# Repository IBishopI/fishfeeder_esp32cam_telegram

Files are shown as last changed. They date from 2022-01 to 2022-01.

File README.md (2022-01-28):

# Fish feeder
My Badge

>Fish feeder based on ESP32CAM dev kit and controlled through telegram bot

### Authors: 
[IBishopI](https://github.com/IBishopI) and [Marina Ursu](https://github.com/marinaursu)

## Description:

This project is aimed at people who love:smiling_face_with_three_hearts: aquarium fish:tropical_fish: but spend too much time at work or on business trips.
An autonomous feeder makes it possible to feed your pets from anywhere in the world.

## Capabilities:
- [x]  Set the feeding portion
- [x]  Schedule feeding once a day
- [x]  Take a picture (with and without flash)
- [x]  Find out the status and time of the last feeding
- [X]  (28.01.2022) Clearing the blockage
- [ ]  (further release) Light and thermostat control
- [ ]  (further release) Measurement of water temperature
- [ ]  (further release) Battary cell life-time and life-keeping functions

### Software requirements:
- Arduino IDE 1.8 and higher [here](https://www.arduino.cc/en/software)
- ESP32 core 1.0.6 (most stable for my opinion) [github](https://github.com/espressif/arduino-esp32) or [json](https://raw.githubusercontent.com/espressif/arduino-esp32/gh-pages/package_esp32_index.json)
- [Universal Telegram Bot library](https://github.com/witnessmenow/Universal-Arduino-Telegram-Bot)
- CH340 driver if you will use USBASP programmer with ch340 chip - [Windows](https://sparks.gogo.co.nz/assets/_site_/downloads/CH34x_Install_Windows_v3_4.zip), [Mac](https://github.com/adrianmihalko/ch340g-ch34g-ch34x-mac-os-x-driver/raw/master/CH34x_Install_V1.5.pkg), [Linux](https://sparks.gogo.co.nz/assets/_site_/downloads/CH340_LINUX.zip "Already built in kernel but if isnt you can download it by click this link") or you can findout it on [official website](http://www.wch.cn/download/ch341ser_zip.html)
- Telegram app on your phone:iphone: or laptop:computer:

### Hardware requirements:
- USB ASP progremmer

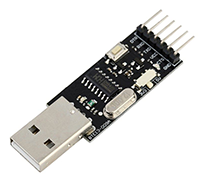
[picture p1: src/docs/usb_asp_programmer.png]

- ESP32cam

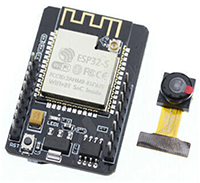
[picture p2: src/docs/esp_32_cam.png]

- Servo

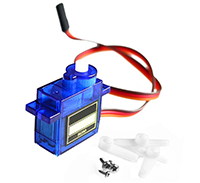
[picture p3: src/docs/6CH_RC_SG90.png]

- DC-DC stepup converter 3.7 to 5v

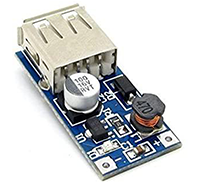
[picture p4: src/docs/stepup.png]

- Battary charger TP4056

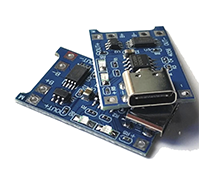
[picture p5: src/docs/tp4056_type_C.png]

- :battery:Li-ion battary cell (18650)

## How to setup telegram bot
> In telegram app find "@BotFather", click/type: /start 
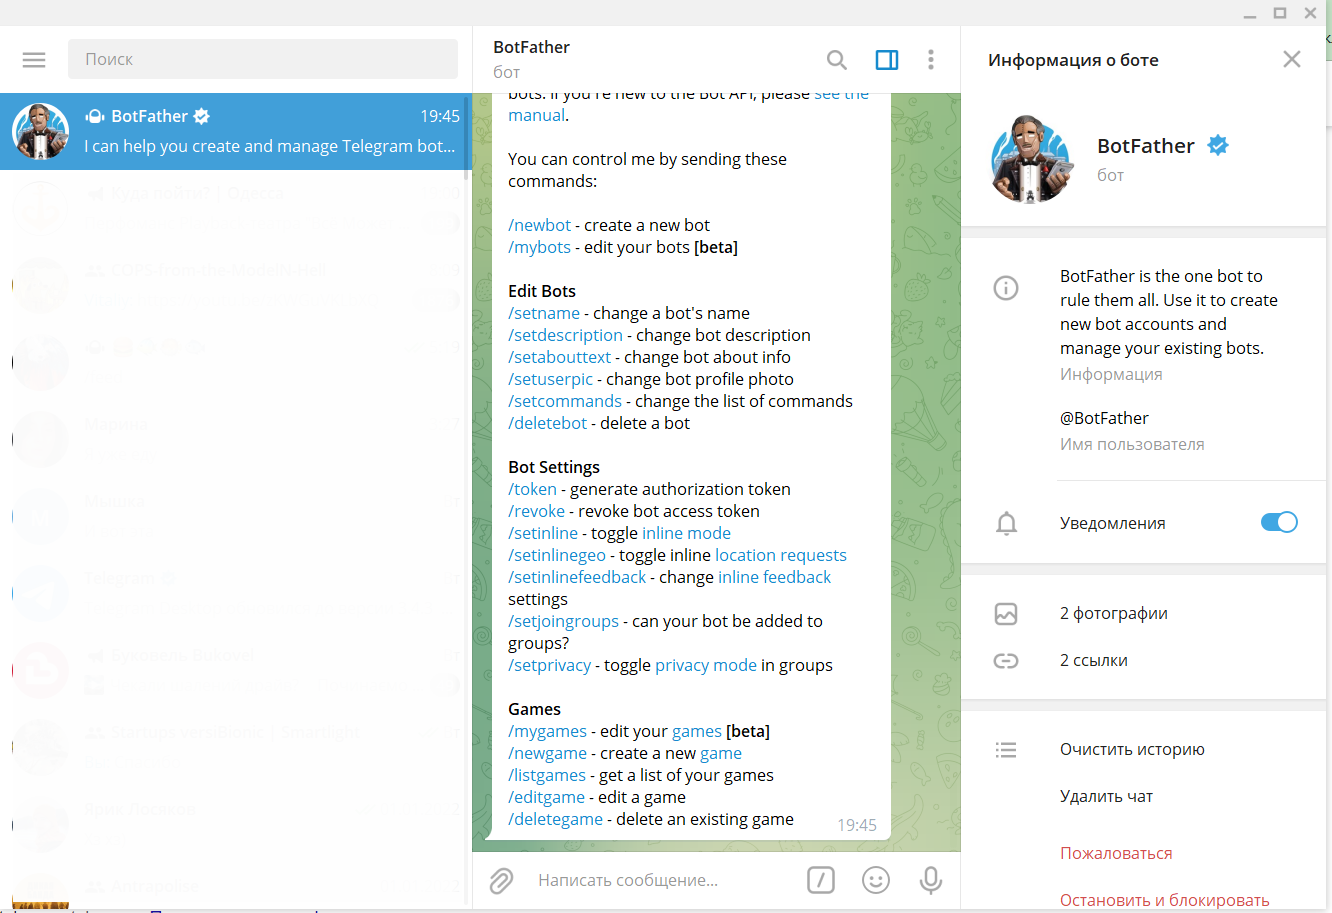
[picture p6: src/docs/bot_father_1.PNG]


> Then click/type command: /newbot
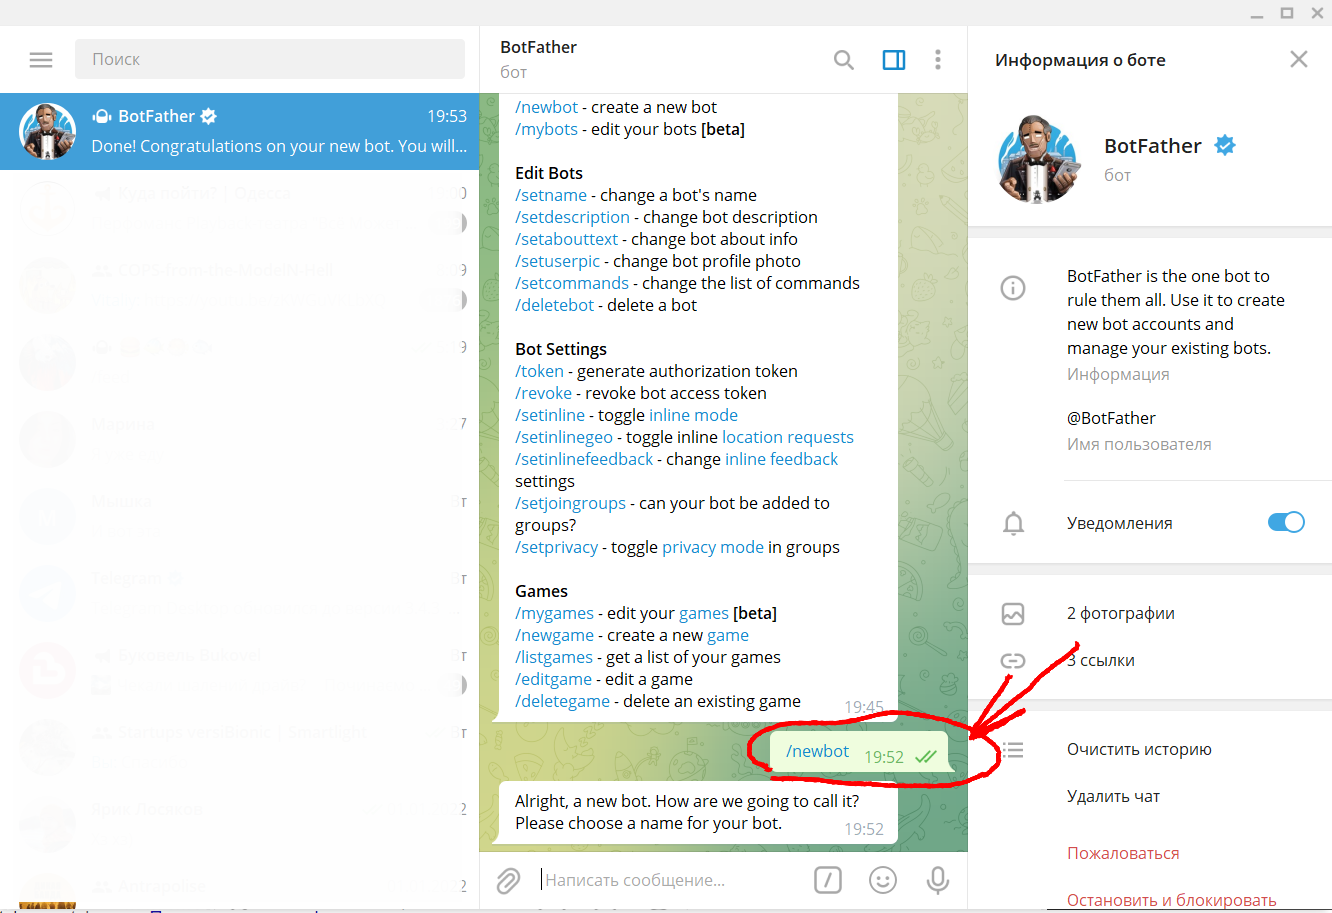
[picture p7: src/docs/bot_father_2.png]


> Then reply to bot's messages, like enter: nickname for bot, username for bot (you can specify any name/username that you want)
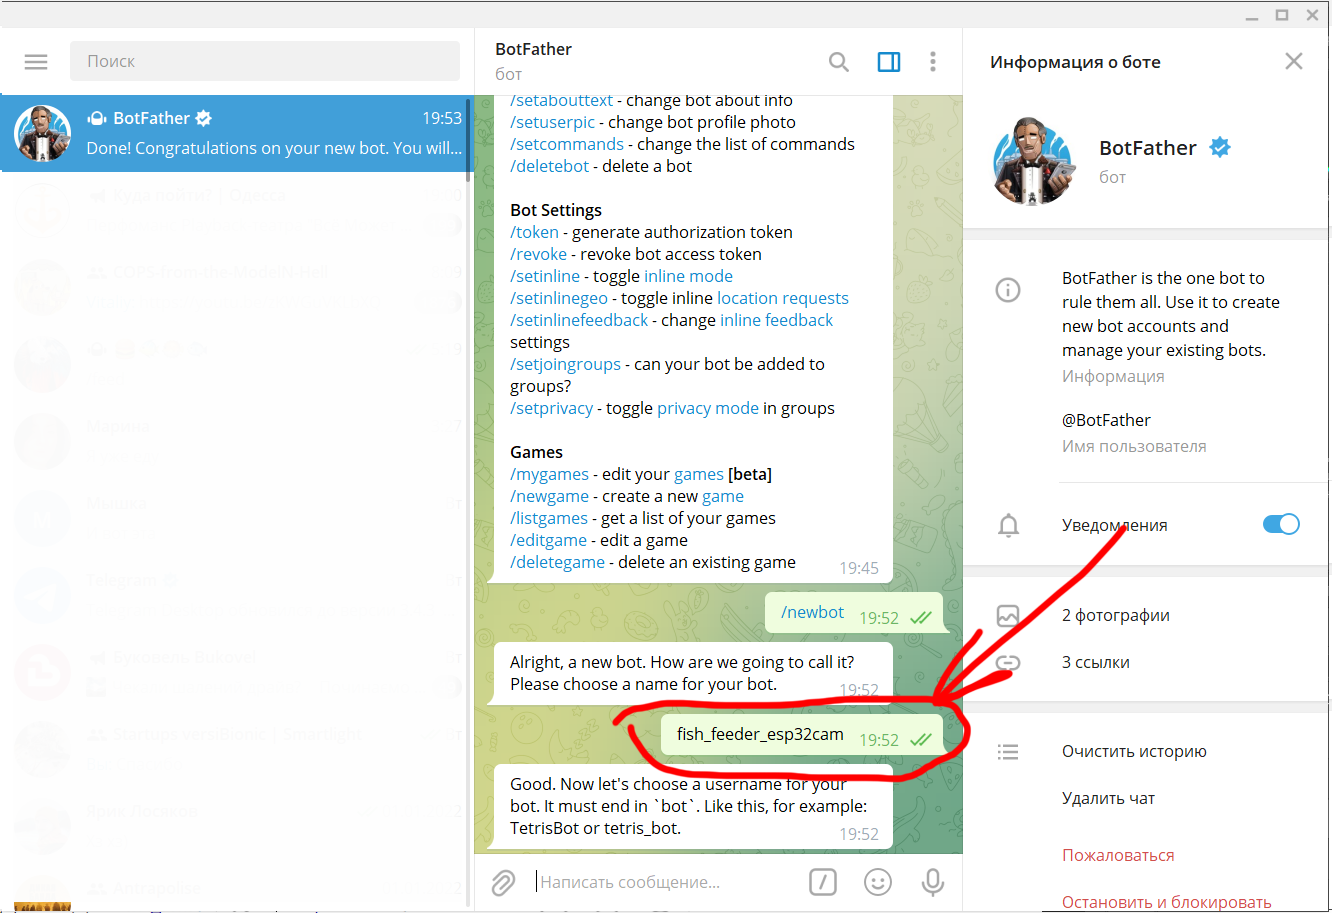
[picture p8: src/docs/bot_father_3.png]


> After that you will get api-token, you should copy it to [this line](https://github.com/IBishopI/fishfeeder_esp32cam_telegram/blob/1f3482a3206f5d00bdcbed5298e4f268f3639a8e/src/Arduino%20IDE%20code/fishfeeder_esp32cam.ino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) in sketch
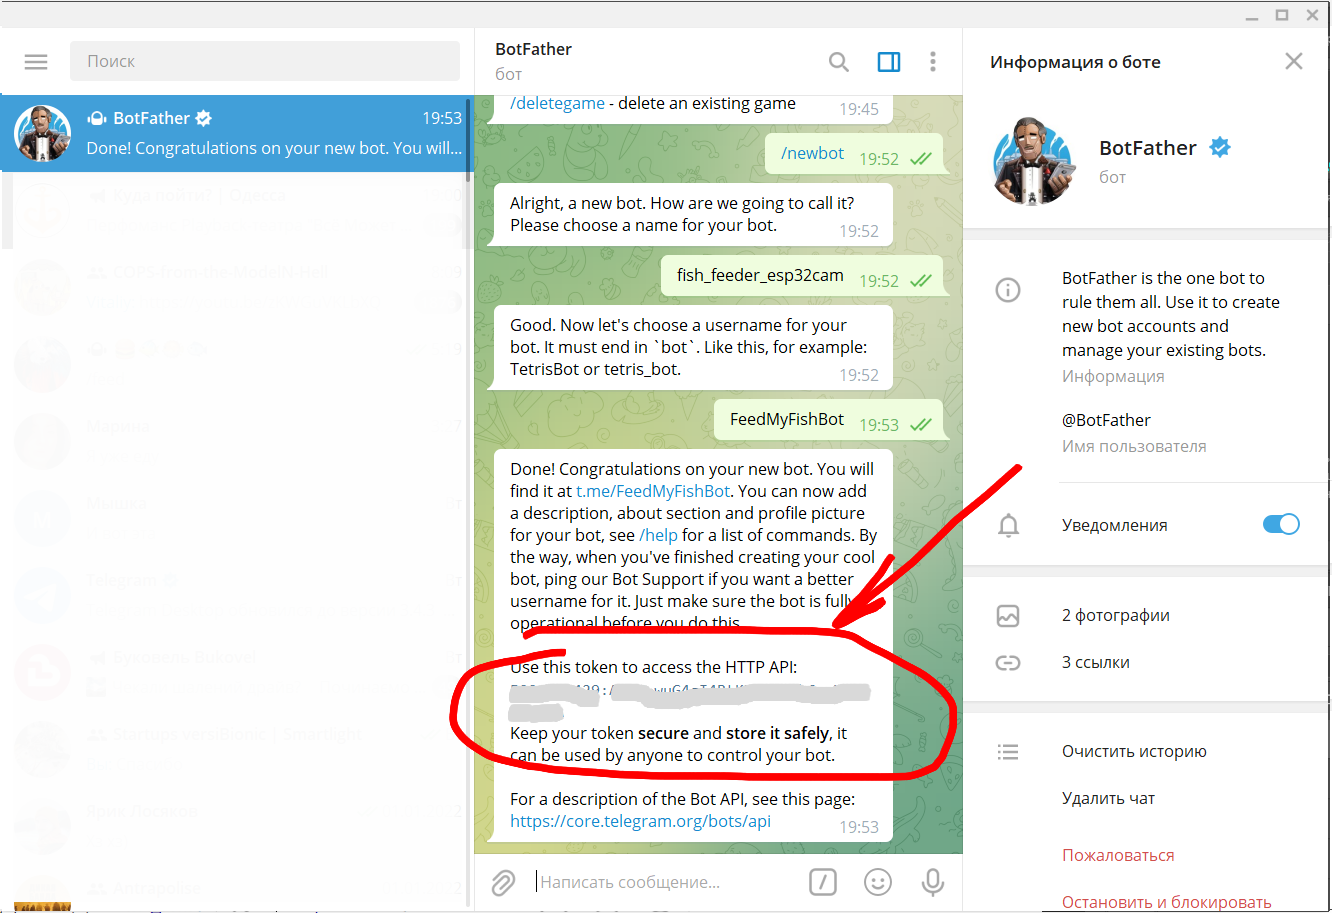
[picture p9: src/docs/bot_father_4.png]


> Setting bot menu: like that (type: /setcommands)
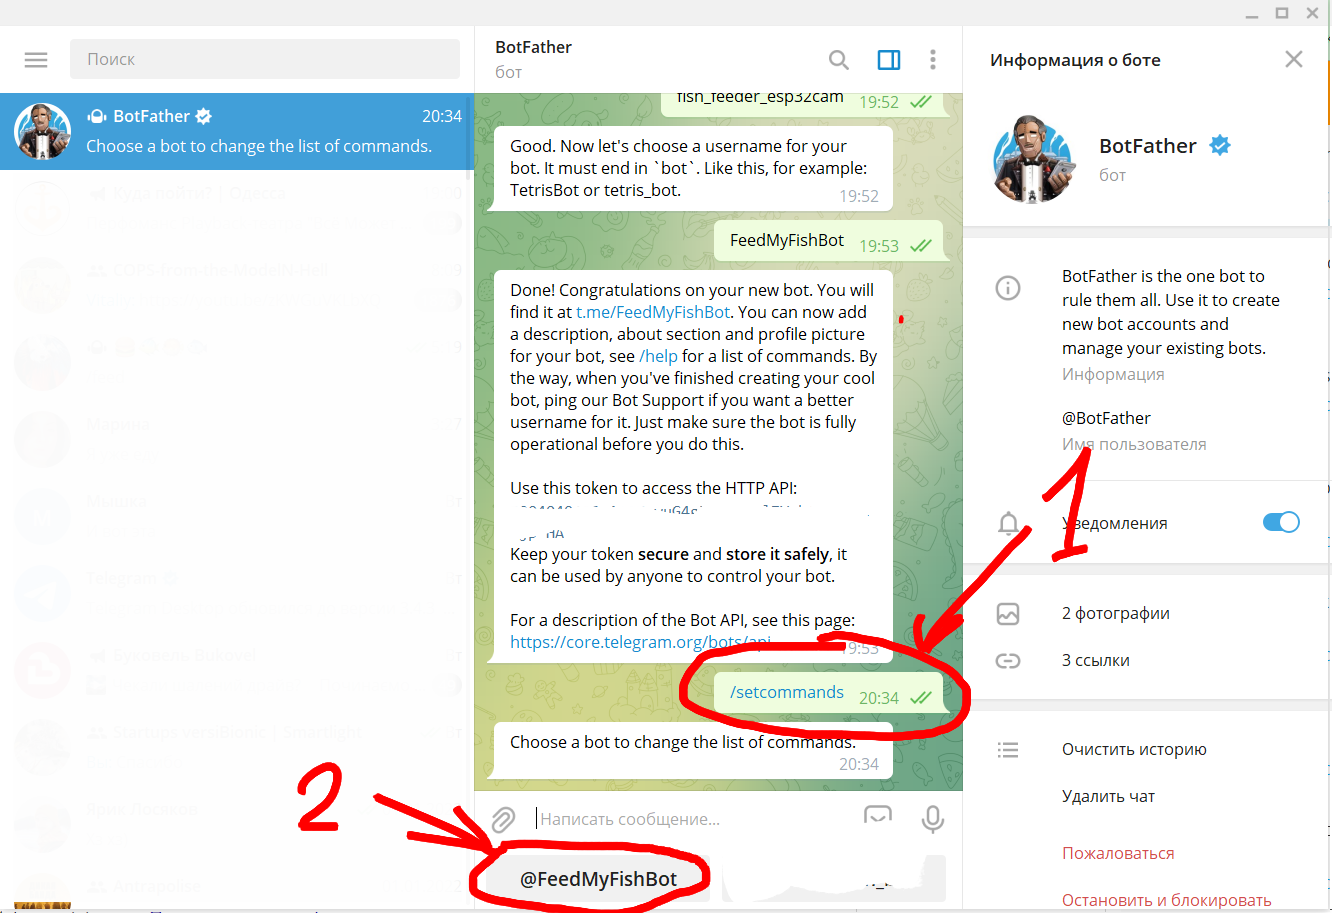
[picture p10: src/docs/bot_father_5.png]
> 

```
flash - enable / disable flash
photo - Take a picture
feed - Feed the fish
schedule - Schedule a feed
feedsize - Set portion
status - Display current information
wobble - Clean feeder
reboot - Restart device
q1 - photo quality 320х240
q2 - photo quality 640х480
q3 - photo quality 800x600 (non-stable)
q4 - photo quality 1024x768 (unsupported by telegram bot API)
q5 - photo quality 1600x1200 (unsupported by telegram bot API)
```
>  
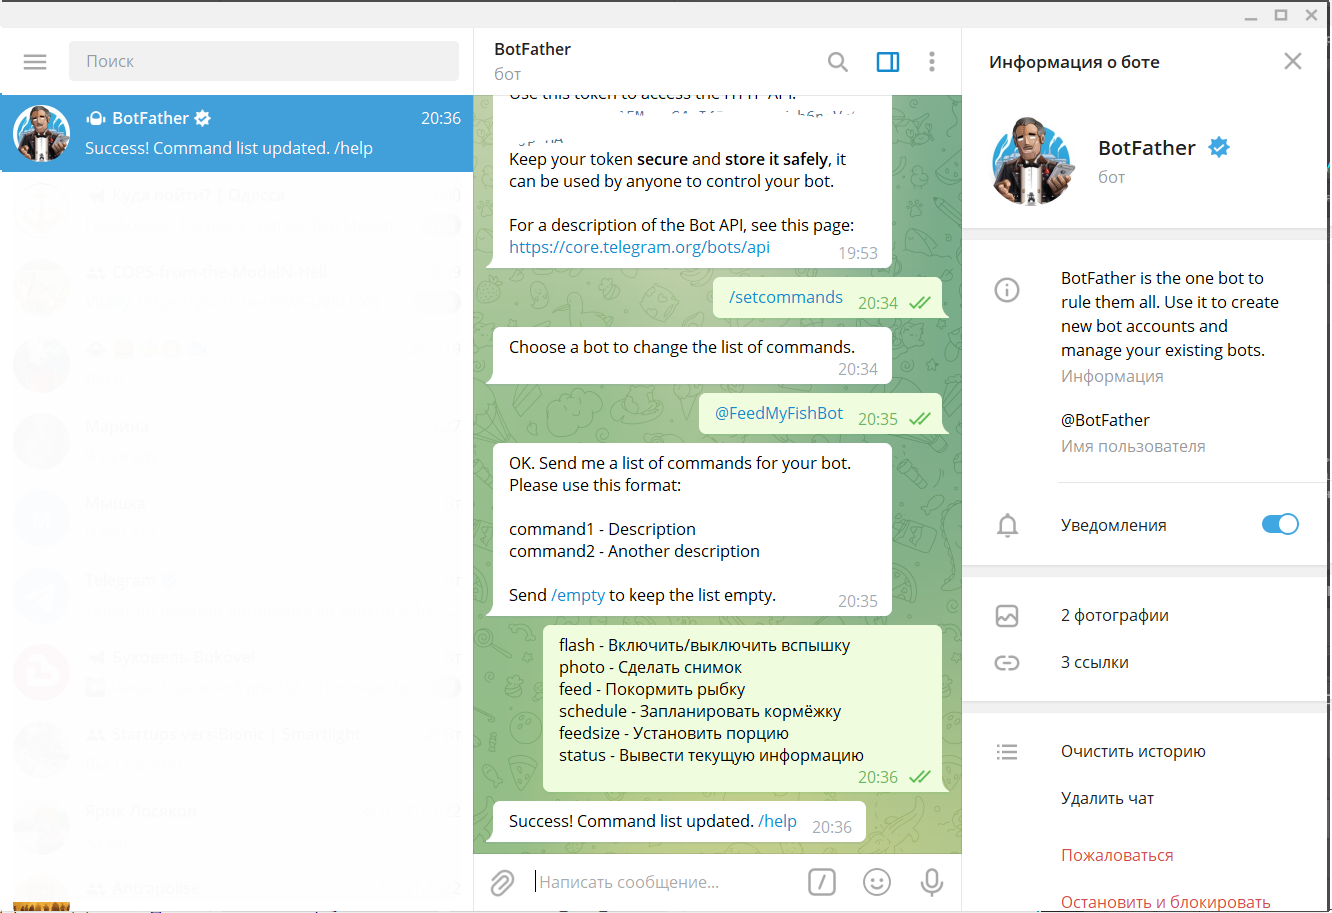
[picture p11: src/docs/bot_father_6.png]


> After that you need to know your personal chat_id. Also you can get groupid or get chat_id's from multiple accounts for users who would get access to your fish feeder.

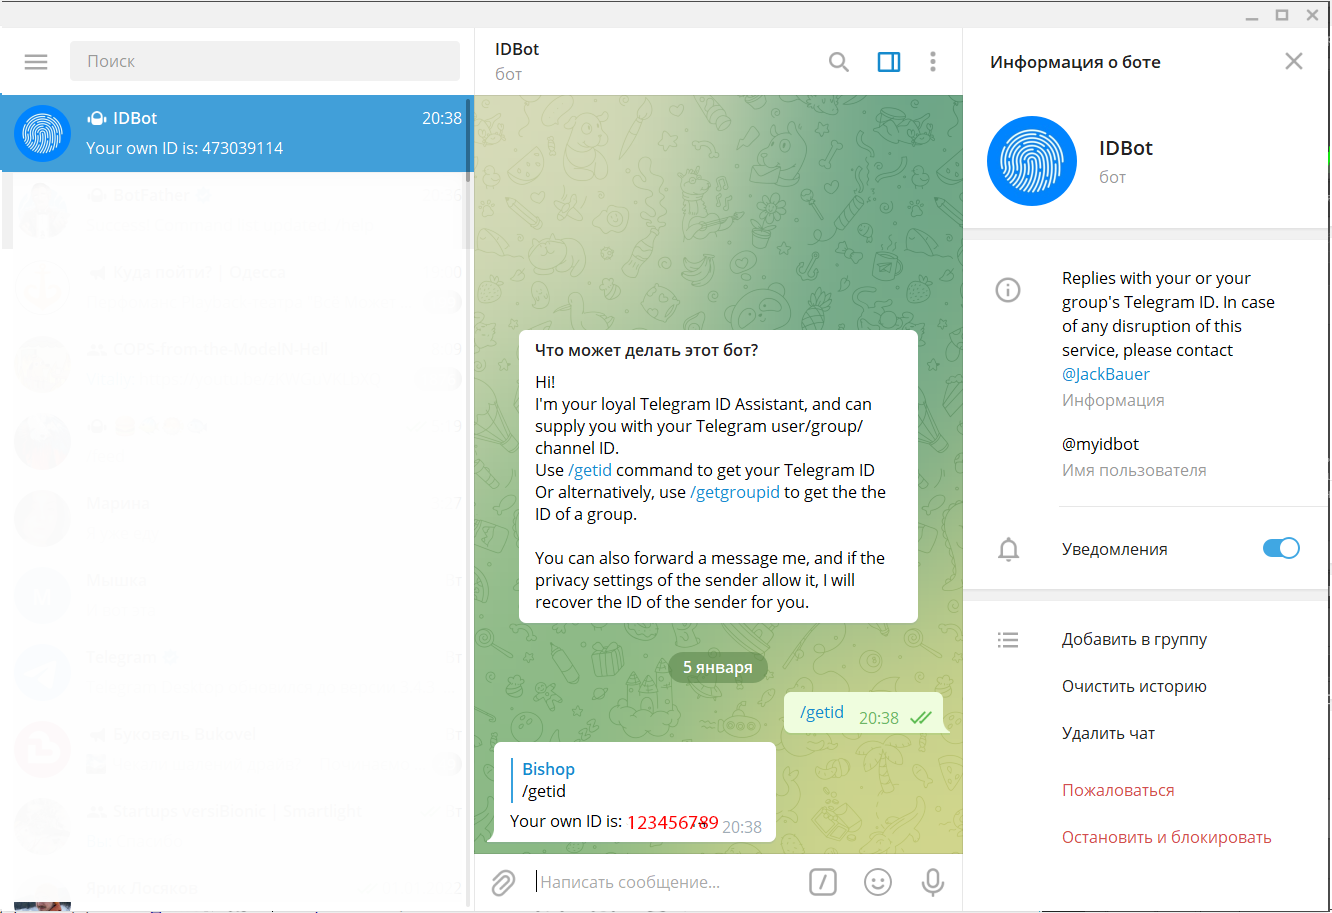
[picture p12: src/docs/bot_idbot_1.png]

> You need to put this id/id's to line [who can access](https://github.com/IBishopI/fishfeeder_esp32cam_telegram/blob/1f3482a3206f5d00bdcbed5298e4f268f3639a8e/src/Arduino%20IDE%20code/fishfeeder_esp32cam.ino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) and set chat_id for bot reply when fish fed by schedule [this one](https://github.com/IBishopI/fishfeeder_esp32cam_telegram/blob/1f3482a3206f5d00bdcbed5298e4f268f3639a8e/src/Arduino%20IDE%20code/fishfeeder_esp32cam.ino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)

## How to upload sketch to esp32cam

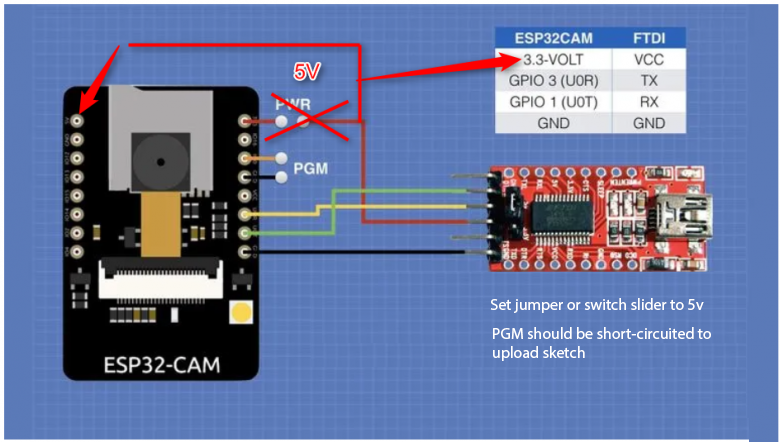
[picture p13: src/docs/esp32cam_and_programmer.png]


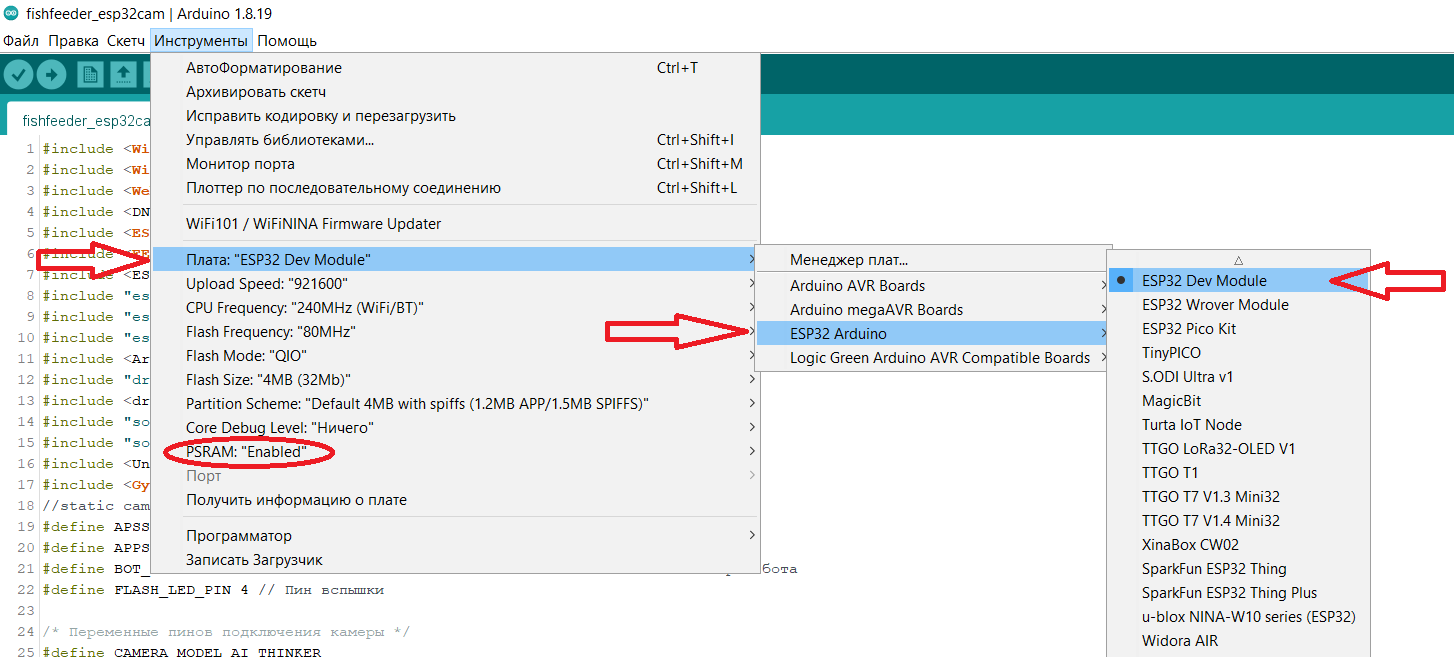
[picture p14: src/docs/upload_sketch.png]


## How to solder components

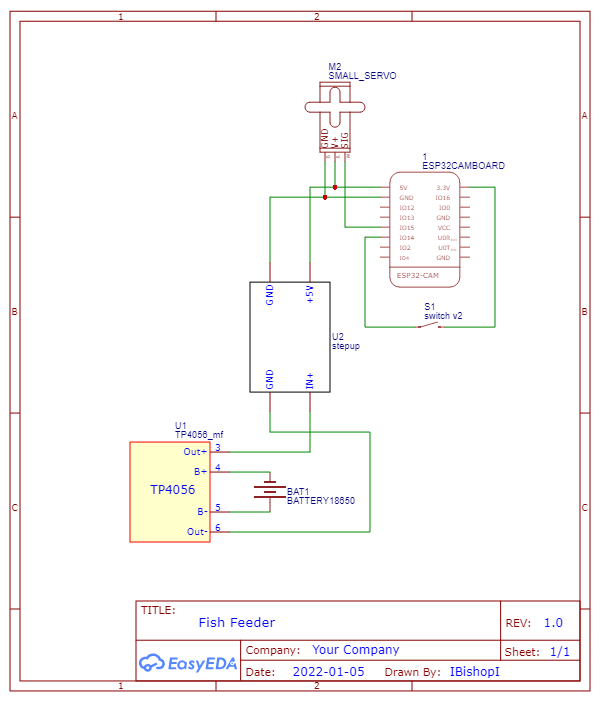
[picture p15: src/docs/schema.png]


## Materials and tools:
- plastic bottle - 38mm neck (volume related how big your aquarium and how many fish do you have, I'm using 330ml and 500ml bottles for aquarium 40L)

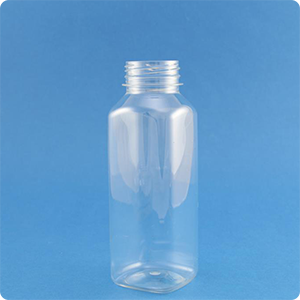
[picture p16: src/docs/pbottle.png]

- FDM 3D printer
- PLA/ABS plastic
- solder

## Construct photos
> Bot screenshot
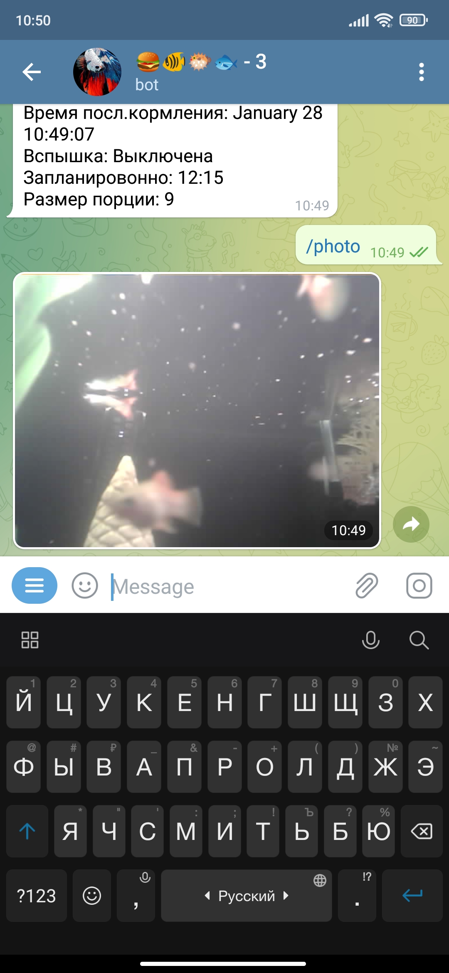
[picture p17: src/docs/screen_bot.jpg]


> Photos
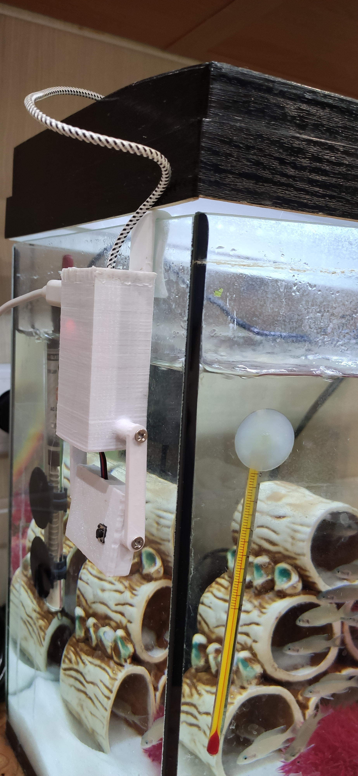
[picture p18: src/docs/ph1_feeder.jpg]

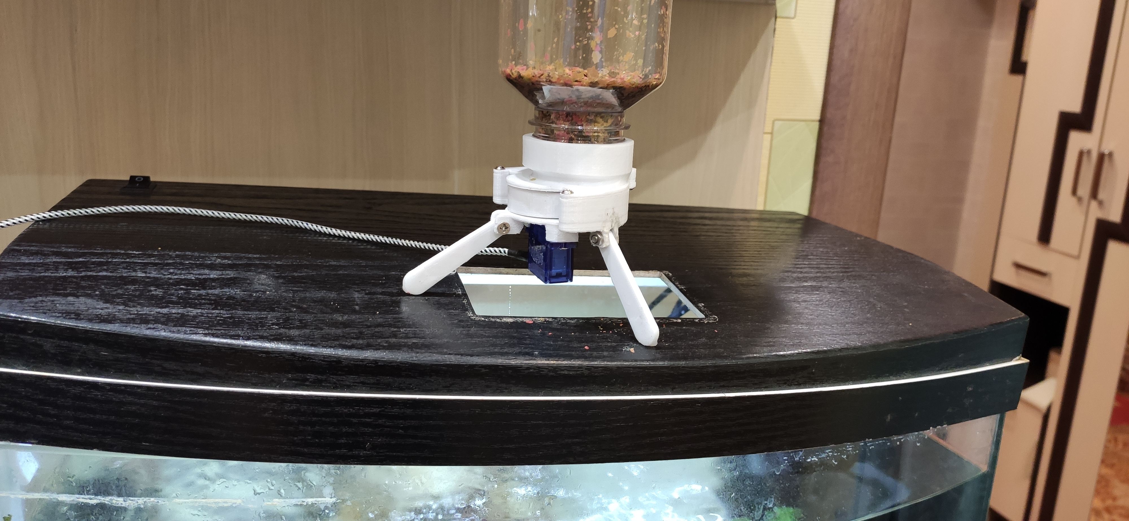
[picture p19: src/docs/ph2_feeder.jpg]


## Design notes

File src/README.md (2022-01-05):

# Fish feeder
My Badge

- > 3d_models           - Directory with 3d models of feeder
- > Arduino IDE code    - main sketch for Arduino IDE
- > docs                - images for github

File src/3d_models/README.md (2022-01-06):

# Fish feeder
My Badge

## Assmbled model
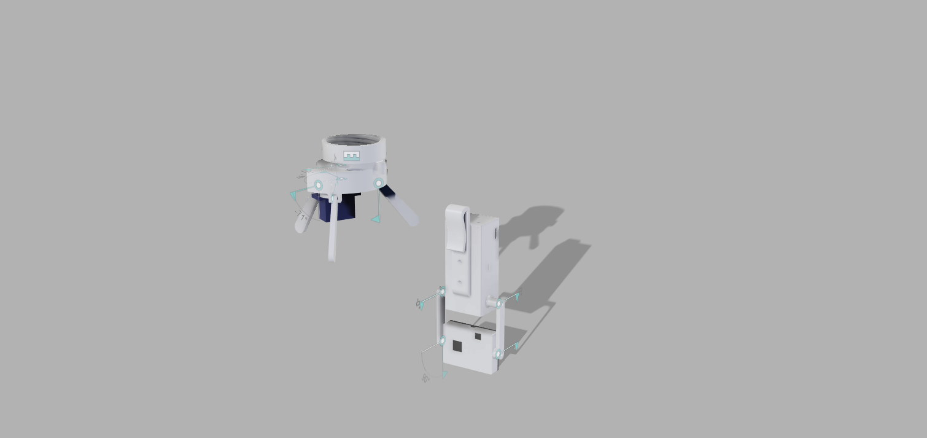
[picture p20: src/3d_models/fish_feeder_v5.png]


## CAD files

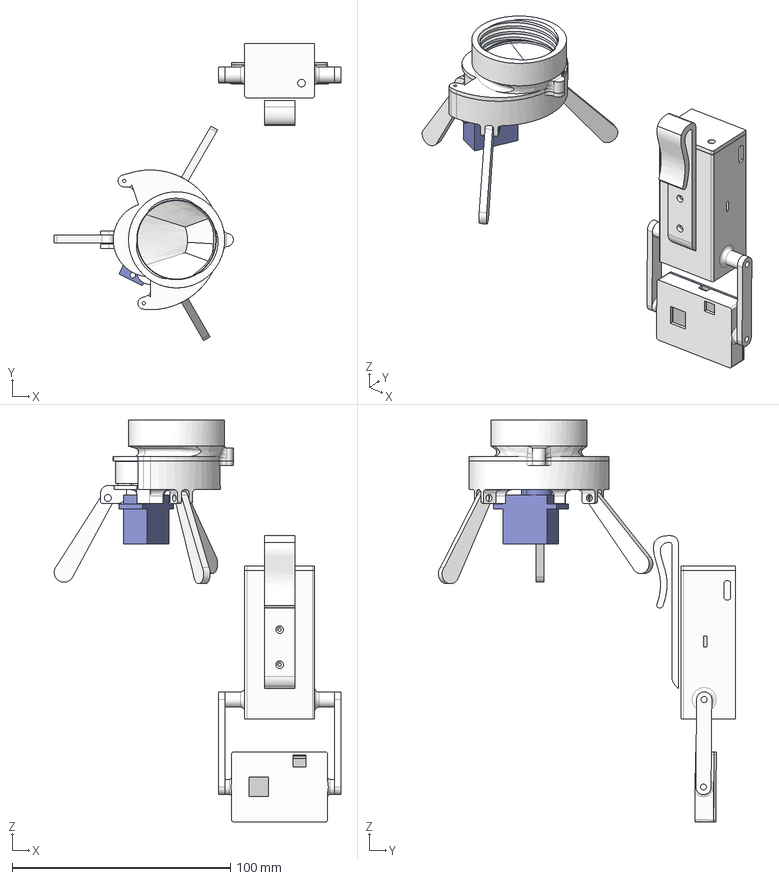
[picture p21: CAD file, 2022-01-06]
src/3d_models/fish_feeder_finished assembly.step
131.2 x 136.2 x 184.0 mm
motor
feeder
body_base
leg x 3
bottom_body
battary_frame
bat_cam_leg_1
bat_cam_leg_2
camera_frame

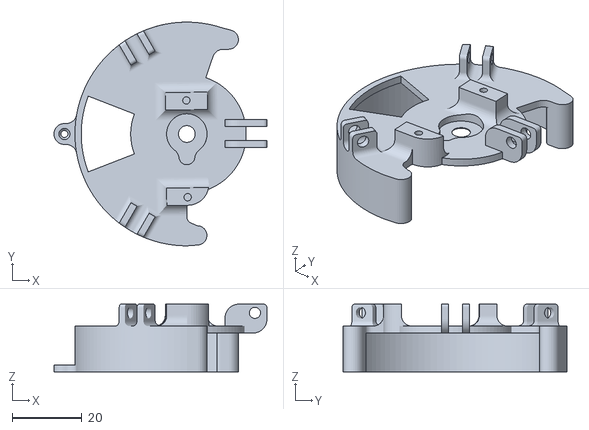
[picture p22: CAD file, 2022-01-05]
src/3d_models/bottom_body.stl
60.9 x 64.0 x 19.4

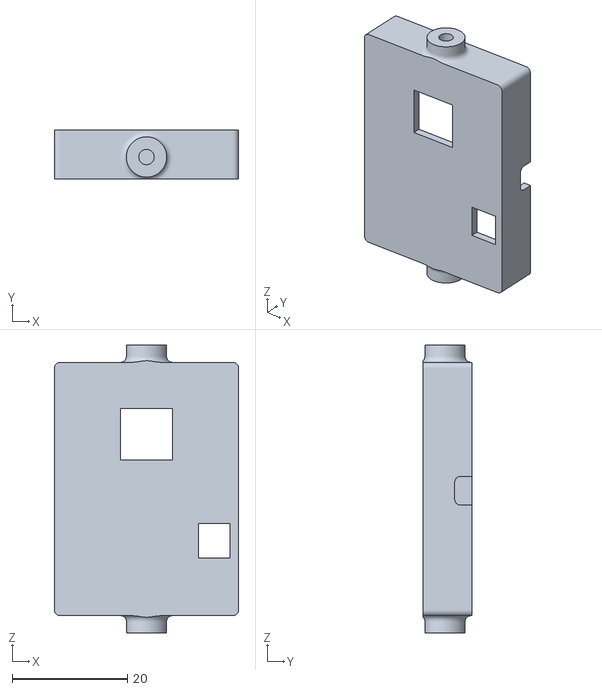
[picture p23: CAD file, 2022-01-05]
src/3d_models/camera_frame.stl
32.0 x 8.50 x 50.0

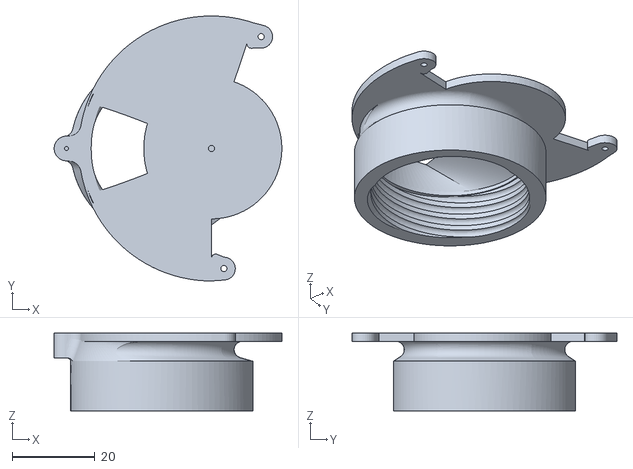
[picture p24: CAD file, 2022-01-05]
src/3d_models/body_base.stl
55.0 x 64.0 x 18.8

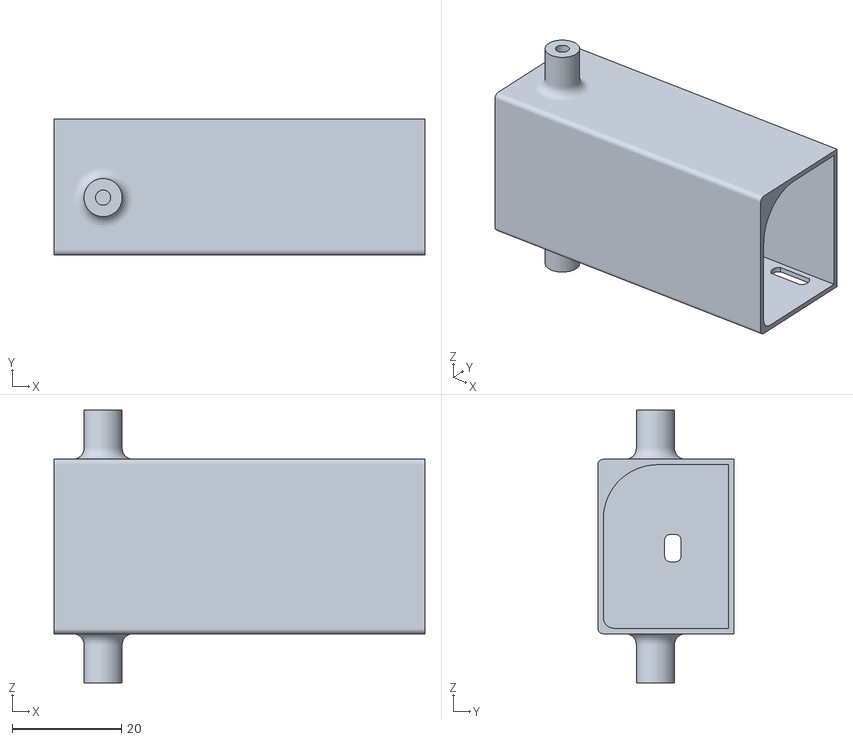
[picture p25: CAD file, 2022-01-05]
src/3d_models/battary_frame.stl
68.0 x 25.0 x 50.0

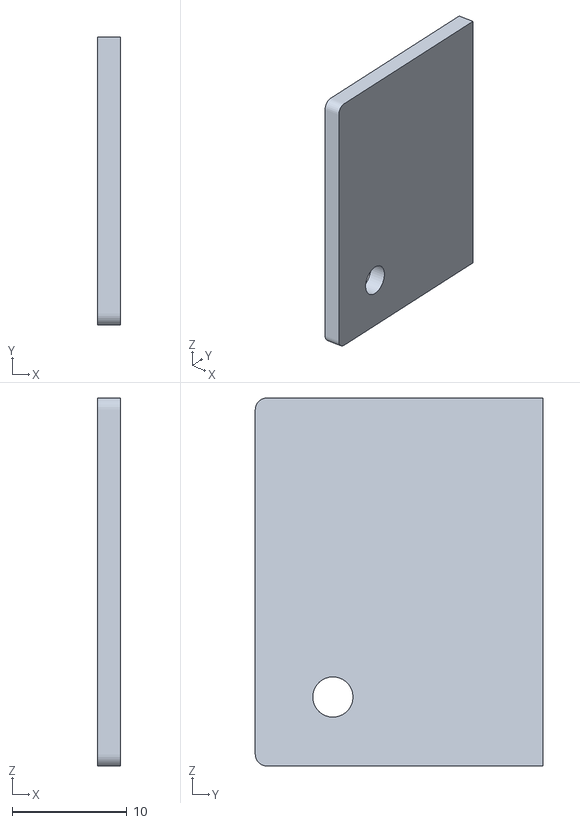
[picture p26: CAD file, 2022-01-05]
src/3d_models/battary_frame_cover.stl
2.00 x 25.0 x 32.0

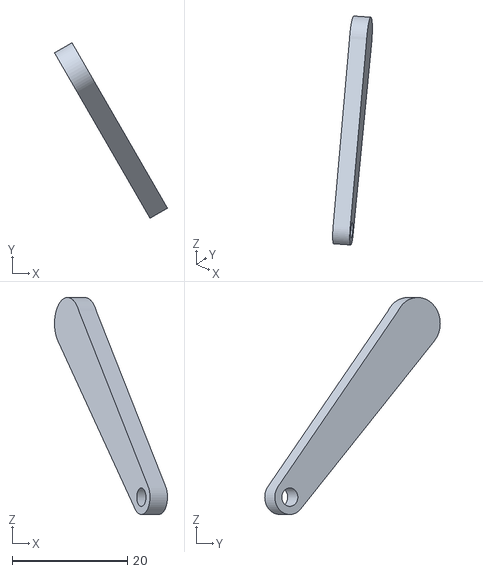
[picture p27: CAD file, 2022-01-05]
src/3d_models/leg.stl
19.6 x 30.4 x 37.6

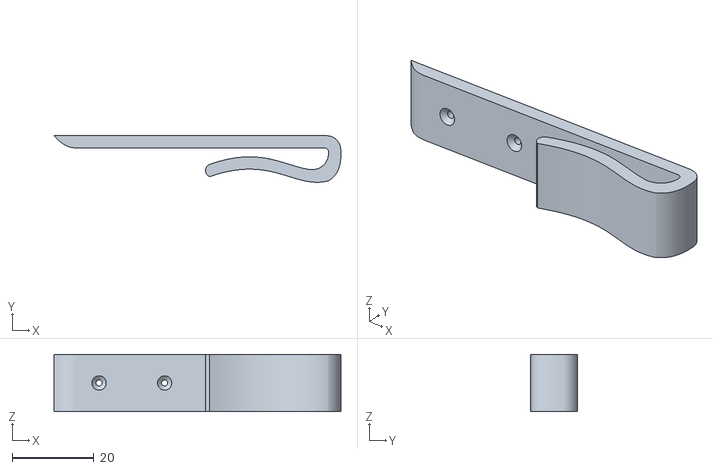
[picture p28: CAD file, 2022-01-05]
src/3d_models/locker.stl
70.0 x 11.4 x 14.0

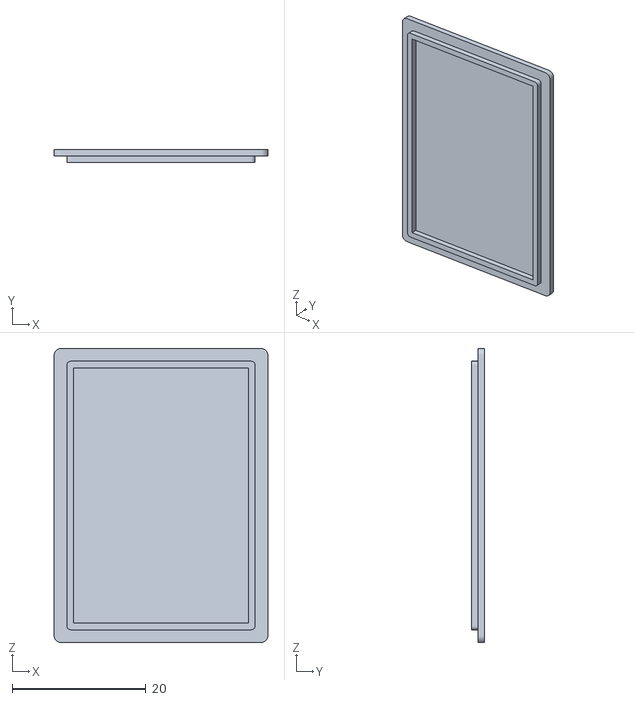
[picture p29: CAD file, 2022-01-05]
src/3d_models/camera_frame_cover.stl
32.0 x 2.00 x 44.0

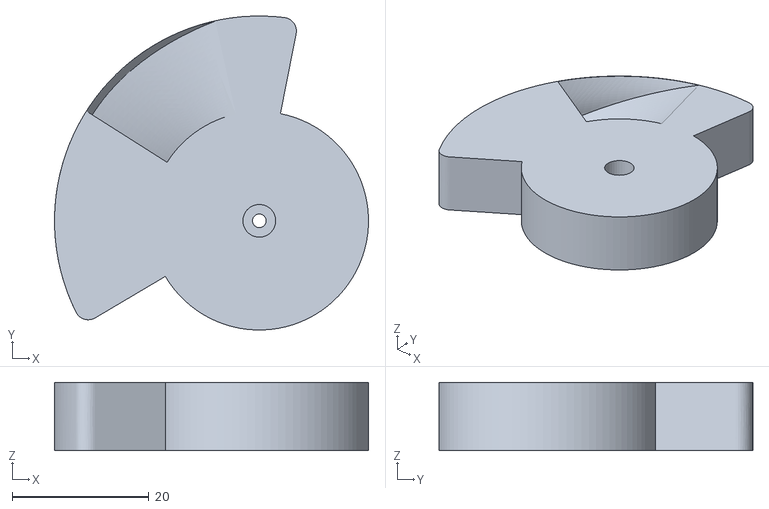
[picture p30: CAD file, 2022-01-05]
src/3d_models/feeder.stl
46.0 x 46.0 x 10.0

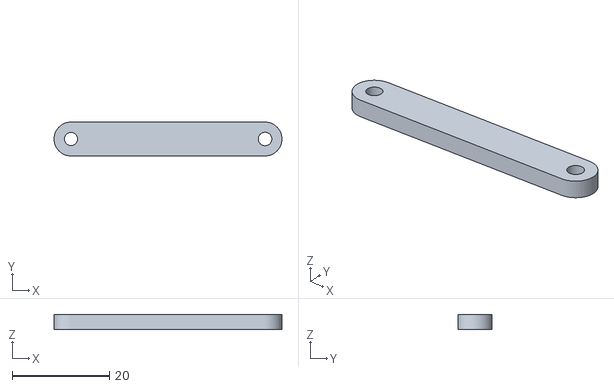
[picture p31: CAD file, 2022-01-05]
src/3d_models/bat_cam_leg_1.stl
47.0 x 7.00 x 3.00

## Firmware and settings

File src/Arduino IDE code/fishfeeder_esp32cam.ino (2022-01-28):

#include <WiFi.h>
#include <WiFiClientSecure.h>
#include <WebServer.h>
#include <DNSServer.h>
#include <ESPmDNS.h>
#include <EEPROM.h>
#include "esp_camera.h"
#include "esp_pm.h"
#include "esp_http_server.h"
#include <ArduinoJson.h>
#include "driver/rtc_io.h"
#include <driver/adc.h>
#include "soc/soc.h"             
#include "soc/rtc_cntl_reg.h" 
#include <UniversalTelegramBot.h>
#include <GyverButton.h>
//static camera_config_t camera_example_config;
#define APSSID "fishfeeder" //Имя точки доступа
#define APPSK  "10203040" //Пароль точки доступа
#define BOT_TOKEN "xxxxxxxx:XXXXXXXXXXXXXXXXXXXXXXXXXXXXXXXXXX" //Токен телеграм бота
#define FLASH_LED_PIN 4 // Пин вспышки

/* PWM vars for servo */
const int servoPin = 15;
int dutyCycle = 0;
const int PWMFreq = 50;
const int PWMChannel = 2;
const int PWMResolution = 8;
const int MAX_DUTY_CYCLE = (int)(pow(2, PWMResolution) - 1);


/* Переменные пинов подключения камеры */
#define CAMERA_MODEL_AI_THINKER
#define PWDN_GPIO_NUM 32
#define RESET_GPIO_NUM -1
#define XCLK_GPIO_NUM 0
#define SIOD_GPIO_NUM 26
#define SIOC_GPIO_NUM 27
#define Y9_GPIO_NUM 35
#define Y8_GPIO_NUM 34
#define Y7_GPIO_NUM 39
#define Y6_GPIO_NUM 36
#define Y5_GPIO_NUM 21
#define Y4_GPIO_NUM 19
#define Y3_GPIO_NUM 18
#define Y2_GPIO_NUM 5
#define VSYNC_GPIO_NUM 25
#define HREF_GPIO_NUM 23
#define PCLK_GPIO_NUM 22
#define ARR_SIZE(a) (sizeof(a) / sizeof(a[0])) // Лямбда возвращающая размер массива
camera_config_t camera_example_config; // Инициализация структуры настроек, воизбежании ошибок с функциями
struct tm timeinfo;
const byte inPins = 14; // Кнопка сброса настроек WIFI
const char *myHostname = APSSID; // hostname устройства
const char *softAP_ssid = APSSID; //Имя точки доступа
const char *softAP_password = APPSK; //Пароль точки доступа
int buttonHoldTime = 5000; //5 секунд зажатие кнопки для сброса настроек
unsigned long pressedtime = 0; // таймер нажатой кнопки
unsigned long scndtimer = 0;
byte wl_delay_counter = 0;
bool exist_cred = false; // если натройки существуют
char ssid[32] = ""; //инициализация переменных под чтение данных из EEPROM
char password[32] = ""; //инициализация переменных под чтение данных из EEPROM
const byte DNS_PORT = 53; // DNS порт
IPAddress apIP(8, 8, 8, 8); // IP - адресс точки доступа
IPAddress netMsk(255, 255, 255, 0); // Маска подсети точки доступа
//Servo feedservo; //объявляем объект feedservo из класса Servo
WebServer server(80); //Объект сервер из класса вэб-сервер
DNSServer dnsServer; // Объект днс-сервера
byte conn_counter=0;
/* Служебные переменные WIFI */
char *wifi_states[] = {"WL_IDLE_STATUS","WL_NO_SSID_AVAIL","WL_SCAN_COMPLETED","WL_CONNECTED","WL_CONNECT_FAILED","WL_CONNECTION_LOST","WL_DISCONNECTED"};
boolean connect;
unsigned long lastConnectTry = 0;
unsigned int status = WL_IDLE_STATUS;
char scheduled_time[16] ="";
char feedsize_f_for_eeprom[16] = "";
const unsigned long BOT_MTBS = 1000; // Интервал между сканированиями сообщений у бота в ms (1000ms = 1 sec)
unsigned long feeder_tmr,flash_tmr,cam_tmr;
unsigned long bot_lasttime; // Дата последней проверки сообщений у бота
WiFiClientSecure secured_client; //Объект SSL соединения
UniversalTelegramBot bot(BOT_TOKEN, secured_client); //Объект телеграм бота
bool flashState = LOW,wflag=false,woflag=false,fflag=false,foflag=false,cflag=false,coflag=false,schedule_feed_state=false,dataAvailable = false,flash_state_enabled=false, schedule_exist=false,ap_mode_flag=false; // переменные состояний
camera_fb_t *fb = NULL; // Очищаем буффер камеры
String previous_message,my_message,lastFeedTime,scheduled_time_str; // Переменные планировщика кормления
int chat_allowed_ids[] = {XXXXXXXXXXX,YYYYYYYYY,ZZZZZZZZZZZ}; // Разрешенные чаты пользователей для работы с ботом (получите у бота @IDBot)
String chat_id_to_response = "YYYYYYYYYYYY"; // Chatid для отправки сообщений в режиме запланированного кормления
int scheduled_time_arr[3] = {0,0}, feed_sizes[] = {130,135,140,145,150,155,160,165,170,175,180}, feedsize_f=5; // Служебные переменные для кормления, массив с градусами для серво а индекс это размер порции
bool isMoreDataAvailable();
byte *getNextBuffer();
int getNextBufferLen();

/* Служебные функции */
/* ----------------------------------------------------------- */
/** Проверка являеться ли строка IP адерсом? */
boolean isIp(String str) {
  for (size_t i = 0; i < str.length(); i++) {
    int c = str.charAt(i);
    if (c != '.' && (c < '0' || c > '9')) {
      return false;
    }
  }
  return true;
}
/** конвертация IP в строку */
String toStringIp(IPAddress ip) {
  String res = "";
  for (int i = 0; i < 3; i++) {
    res += String((ip >> (8 * i)) & 0xFF) + ".";
  }
  res += String(((ip >> 8 * 3)) & 0xFF);
  return res;
}
/** Чтение имя WLAN сети и пароля из памяти EEPROM */
void loadCredentials() {
  EEPROM.begin(512);
  char ok[2 + 1];
  EEPROM.get(0, ssid);
  EEPROM.get(0 + sizeof(ssid), password);
  EEPROM.get(0 + sizeof(ssid) + sizeof(password),scheduled_time);
  EEPROM.get(0 + sizeof(ssid) + sizeof(password) + sizeof(scheduled_time), feedsize_f_for_eeprom);
  EEPROM.get(0 + sizeof(ssid) + sizeof(password) + sizeof(scheduled_time) + sizeof(feedsize_f_for_eeprom), ok);
  EEPROM.end();
  if (String(ok) != String("OK")) {
    ssid[0] = 0;
    password[0] = 0;
  }
  Serial.println("Recovered credentials:");
  Serial.println(ssid);
  Serial.println(strlen(password) > 0 ? "********" : "<no password>");
  if (strlen(password) > 0) {
    exist_cred = true;
    }
  if(strlen(scheduled_time) > 0) {
        scheduled_time_arr[0] = getValue(scheduled_time, ':', 0).toInt();
        scheduled_time_arr[1] = getValue(scheduled_time, ':', 1).toInt();
        scheduled_time_str = scheduled_time;
        Serial.print("Recovered schedule: ");
        Serial.println(scheduled_time);
    }
  if(strlen(feedsize_f_for_eeprom) > 0) { 
    feedsize_f = atoi(feedsize_f_for_eeprom); Serial.print("Recovered feedsize: "); Serial.println(feedsize_f);
    }
}
/** Сохранение WLAN имя/пароля в EEPROM */
void saveCredentials() {
  EEPROM.begin(512);
  char ok[2 + 1] = "OK";
  EEPROM.put(0, ssid);
  EEPROM.put(0 + sizeof(ssid), password);
  EEPROM.put(0 + sizeof(ssid) + sizeof(password),scheduled_time);
  EEPROM.put(0 + sizeof(ssid) + sizeof(password) + sizeof(scheduled_time), feedsize_f_for_eeprom);
  EEPROM.put(0 + sizeof(ssid) + sizeof(password) + sizeof(scheduled_time) + sizeof(feedsize_f_for_eeprom), ok);
  EEPROM.commit();
  EEPROM.end();
}
/** Конфигурация и инициализация камеры  */
extern "C" { esp_err_t camera_enable_out_clock(camera_config_t *config); void camera_disable_out_clock(); }

esp_err_t my_camera_init() {
  //power up the camera if PWDN pin is defined
  if (PWDN_GPIO_NUM != -1) {
    gpio_pad_select_gpio(PWDN_GPIO_NUM);
    gpio_set_direction((gpio_num_t)PWDN_GPIO_NUM, GPIO_MODE_OUTPUT);
    gpio_set_level((gpio_num_t)PWDN_GPIO_NUM, 0);
 }
  esp_err_t err = esp_camera_init(&camera_example_config);
  if (err != ESP_OK) {
    Serial.printf("Camera init failed with error 0x%x", err);
    return err;
  }
  Serial.printf("Camera Init OK");
  return ESP_OK;
}

/** Функции обработки страниц вэб сервера */
//const String csstyle = F("style=\"border:0;border-radius:0.5rem; background: linear-gradient(to top left, #45609D 0%, #7A91C4 100%);color:#fff;line-height:2.4rem;font-size:1.2rem;width:70%;\""); //CSS 
const String csstyle = F("<style type=\"text/css\"> .div_stl{ width:80%;border:0px;border-radius:0.5rem; box-shadow: rgba(99, 99, 99, 0.3) -4px 4px 3px,rgba(99, 99, 99, 0.5) -1px 1px 2px,inset 0px 0px 1px rgba(0,0,0,0.3); } .btn_stl{border:0;border-radius:0.5rem; background: linear-gradient(to top left, #45609D 0%, #7A91C4 100%);color:#fff;line-height:2.4rem;font-size:1.2rem;width:70%;} .btn_stl:hover{background: linear-gradient(to top left, #699D45 0%, #8DC47A 100%);} </style>"); //CSS 
boolean captivePortal() {
  if (!isIp(server.hostHeader()) && server.hostHeader() != (String(myHostname) + ".local")) {
    Serial.println("Request redirected to captive portal");
    server.sendHeader("Location", String("http://") + toStringIp(server.client().localIP()), true);
    server.send(302, "text/plain", "");   // Empty content inhibits Content-length header so we have to close the socket ourselves.
    server.client().stop(); // Stop is needed because we sent no content length
    return true;
  }
  return false;
}
void handleRoot() {
  if (captivePortal()) { // If caprive portal redirect instead of displaying the page.
    return;
  }
  server.sendHeader("Cache-Control", "no-cache, no-store, must-revalidate");
  server.sendHeader("Pragma", "no-cache");
  server.sendHeader("Expires", "-1");

  String Page;
  Page += String(F("<!DOCTYPE html><html><head>")) + csstyle + String(F("<meta charset=\"utf-8\"><meta name=\"viewport\" content=\"width=device-width, initial-scale=1\"><title>Configuration ")) + myHostname + F("</title>");
  Page += String(F("</head><body><center><div style=\"div_stl\"><h1>Кормилка рыбок</h1>"));
  if (server.client().localIP() == apIP) {
    Page += String(F("<p>Вы подключились к: ")) + softAP_ssid + F("</p>");
  } else {
    Page += String(F("<p>Вы подключились через сеть: ")) + ssid + F("</p>");
  }
  Page += String(F(
            "<br />  <a href=\"/wifi\" target=\"_\"><input type=\"button\" value=\"Настройки\" class=\"btn_stl\"/></a><br><br><font style=\"font-size: 12px;color:#7A91C4;\">Powered by (git):<br>marinaursu & IBishopI</font></div></center></body></html>" ));
  server.send(200, "text/html", Page);
  server.client().stop();
}
void handleWifi() {
  server.sendHeader("Cache-Control", "no-cache, no-store, must-revalidate");
  server.sendHeader("Pragma", "no-cache");
  server.sendHeader("Expires", "-1");

  String Page;
  Page += String(F("<!DOCTYPE html><html><head>")) + csstyle + String(F("<meta charset=\"utf-8\"><meta name=\"viewport\" content=\"width=device-width, initial-scale=1\"></head><body><center><div class=\"div_stl\"><br /><h1>Настройка WiFi</h1>"));
            
  if (server.client().localIP() == apIP) {
    Page += String(F("<p>Вы подключены к: ")) + softAP_ssid + F("</p>");
  } else {
    Page += String(F("<p>Вы подключены через сеть: ")) + ssid + F("</p>");
  }
  Page +=  String(F(
             "\r\n<br />"
             "<p>Выберите свою сеть из списка:</p>"));
  Serial.println("scan start");
  int n = WiFi.scanNetworks();
  Serial.println("scan done");
  Page += String(F(
            "\r\n<form method='POST' action='wifisave'>"
          "<select name='n' style=\"width:70%;background: transparent;padding:5px;font-size:16px;border:1px solid #ccc;height:34px;margin-bottom:5px;\">"));
    if (n > 0) {
    for (int i = 0; i < n; i++) {
      Page += String(F("\r\n<option value=\"")) + WiFi.SSID(i) + F("\">") +  WiFi.SSID(i) + ((WiFi.encryptionType(i) == WIFI_AUTH_OPEN) ? F(" [open ") : F(" [wpa ")) + F(" ") + WiFi.RSSI(i) + F("dbm]</option>");
    }
  } else {
    Page += F("<option value=\"none\">(!)Нет доступных сетей</option>");
  }        
  Page += String(F(   "</select><br /><input type='password' placeholder=' пароль' name='p' style=\"width:70%;background: transparent;padding:0px;font-size:16px;border:1px solid #ccc;height:34px;margin-bottom:5px;\"/><br /><input type='submit' value='Подключится' class='btn_stl'/></form><br /><a href='/'><-назад</a></div></center></body></html>"));

  server.send(200, "text/html", Page);
  server.client().stop(); // Stop is needed because we sent no content length
}
void handleWifiSave() {
  Serial.println("wifi save");
  server.arg("n").toCharArray(ssid, sizeof(ssid) - 1);
  server.arg("p").toCharArray(password, sizeof(password) - 1);
  server.sendHeader("Location", "wifi", true);
  server.sendHeader("Cache-Control", "no-cache, no-store, must-revalidate");
  server.sendHeader("Pragma", "no-cache");
  server.sendHeader("Expires", "-1");
  server.send(302, "text/plain", "");    // Empty content inhibits Content-length header so we have to close the socket ourselves.
  server.client().stop(); // Stop is needed because we sent no content length
  saveCredentials();
  delay(300);
  ESP.restart();
}

/** Функция обработки 404 ошибки **/
void handleNotFound() {
  if (captivePortal()) { // If caprive portal redirect instead of displaying the error page.
    return;
  }
  String message = F("File Not Found\n\n");
  message += F("URI: ");
  message += server.uri();
  message += F("\nMethod: ");
  message += (server.method() == HTTP_GET) ? "GET" : "POST";
  message += F("\nArguments: ");
  message += server.args();
  message += F("\n");

  for (uint8_t i = 0; i < server.args(); i++) {
    message += String(F(" ")) + server.argName(i) + F(": ") + server.arg(i) + F("\n");
  }
  server.sendHeader("Cache-Control", "no-cache, no-store, must-revalidate");
  server.sendHeader("Pragma", "no-cache");
  server.sendHeader("Expires", "-1");
  server.send(404, "text/plain", message);
}


/** Служебные функции */
void buttonPressed() {
  if (pressedtime == 0) {
  pressedtime = millis();
  }
  if (pressedtime != 0) {
  scndtimer = millis();
  } else {
  scndtimer = 0;  
  }
while ( ( scndtimer - pressedtime ) > buttonHoldTime ){
Serial.println("Pressed for: ");
Serial.println(( scndtimer - pressedtime ));
digitalWrite(FLASH_LED_PIN, HIGH);
delay(30);
digitalWrite(FLASH_LED_PIN, LOW);
EEPROM.begin(512);
delay(100);
for ( byte i = 0; i < 512; i++ ){
EEPROM.put(i, 0);
delay(25);
EEPROM.commit();
Serial.println( i );
if ( i == 255 ) {
break; 
}}
EEPROM.end();
pressedtime = 0;
ESP.restart();
break;
}}

String printLocalTime(const char* mask)
{
  struct tm timeinfo;
  if(!getLocalTime(&timeinfo)){
    Serial.println("Failed to obtain time");
    return "NTP unavailable";
  }
  char timeStringBuff[50]; 
  strftime(timeStringBuff, sizeof(timeStringBuff), mask, &timeinfo);
  return timeStringBuff;
}

bool isMoreDataAvailable()
{
  if (dataAvailable)
  {
    dataAvailable = false;
    return true;
  }
  else
  {
    return false;
  }
}

byte *getNextBuffer()
{
  if (fb)
  {
    return fb->buf;
  }
  else
  {
    return nullptr;
  }
}

int getNextBufferLen()
{
  if (fb)
  {
    return fb->len;
  }
  else
  {
    return 0;
  }
}

void WIFI_AP_mode() {
  WiFi.mode(WIFI_AP);
  WiFi.softAP(softAP_ssid, softAP_password);
  Serial.println(WiFi.softAPConfig(apIP, apIP, netMsk)? "Configuring Soft AP" : "Error in Configuration");    
  WiFi.softAPIP();
  delay(500); //без задержки пустой IP
  Serial.print("AP IP address: ");
  Serial.println(WiFi.softAPIP());
  ap_mode_flag=true;
  }

 /** Функция подключения к wifi и получения времени с NTP (+ установка сертификата telegram) **/
void connectWifi() {
  if( exist_cred  ) {
  Serial.println("Connecting as wifi client...");
  WiFi.disconnect();
  WiFi.mode(WIFI_STA);
  WiFi.begin(ssid, password);
  int connRes = WiFi.waitForConnectResult();
  Serial.print("connRes: ");
  Serial.println(wifi_states[connRes]);
    while (WiFi.status() != WL_CONNECTED)
  { 
    if(conn_counter==250) { conn_counter=0; ESP.restart(); }
    Serial.print(".");
    delay(500);
    detacher();
    flash_disabler();
    conn_counter++;
  }
  conn_counter=0;
  ap_mode_flag=false;
  secured_client.setCACert(TELEGRAM_CERTIFICATE_ROOT);
    Serial.print("\nWiFi connected. IP address: ");
  Serial.println(WiFi.localIP());
    Serial.print("Retrieving time: ");
  const char* ntpServer = "pool.ntp.org";
  const long  gmtOffset_sec = 7200;
  const int   daylightOffset_sec = 3600;
  configTime(gmtOffset_sec, daylightOffset_sec, ntpServer);
  time_t now = time(nullptr);
  while (now < 24 * 3600)
  {
    Serial.print(".");
    delay(100);
    now = time(nullptr);
  }
  Serial.println(now);
  Serial.println(printLocalTime("%B %d %H:%M:%S"));
  }
  bot.longPoll = 1;
}

bool check_allow(String ch_check) {
  for(int ch = 0; ch < ARR_SIZE(chat_allowed_ids); ch++) {
    if(chat_allowed_ids[ch] == ch_check.toInt()) {
      return true;
      }
    }
  return false;
  }

String getValue(String data, char separator, int index)
{
    int found = 0;
    int strIndex[] = { 0, -1 };
    int maxIndex = data.length() - 1;

    for (int i = 0; i <= maxIndex && found <= index; i++) {
        if (data.charAt(i) == separator || i == maxIndex) {
            found++;
            strIndex[0] = strIndex[1] + 1;
            strIndex[1] = (i == maxIndex) ? i+1 : i;
        }
    }
    return found > index ? data.substring(strIndex[0], strIndex[1]) : "";
}
void wobble_feeder() {
  servo_drive(130);
  delay(200);
  servo_drive(110);
  delay(200);
  servo_drive(140);
  delay(200);
  servo_drive(110);
  delay(200);
  servo_drive(135);
  delay(200);
  servo_drive(110);
  delay(200);
  servo_drive(150);
  delay(200);
  servo_drive(110);
  }
void feed_fish(int feeder_pos, String fchat_id) {
fb = NULL;
servo_drive(feeder_pos);
wflag=true;
bot.sendMessage(fchat_id, "Кормушка 3: покормила!", "Markdown");
}

void detacher() {
  if(wflag) {
    if(!woflag) {
      feeder_tmr = millis();
      woflag=!woflag;
      } else {
        if((millis() - feeder_tmr) >= 1000) {
          Serial.println("Turning back");
          servo_drive(110);
          woflag=!woflag;
          wflag=!wflag;
          } 
//          else if((millis() - feeder_tmr) >= 1100) {
//          Serial.println("Turning back");
//          woflag=!woflag;
//          wflag=!wflag;
//          servo_drive(110);
//            }
        }
    }
}

void flash_disabler() {
  if(fflag) {
    if(!foflag) {
      flash_tmr = millis();
      foflag=!foflag;
      }
    else {
      if((millis() - flash_tmr) >= 1000) {
           flashState = !flashState;
           digitalWrite(FLASH_LED_PIN, flashState);
           Serial.print("Flash state: "); Serial.println(flashState);
           fflag=!fflag;
           foflag=!foflag;
        } 
     }
  }
}


void servo_drive(int pos) {
          dutyCycle = map(pos, 0, 180, 5, 32);
          ledcWrite(PWMChannel, dutyCycle); 
  }
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
void loop()
{
   if(((esp_timer_get_time()/1000000)) >= 172800) {
    ESP.restart();
    }
  detacher();
  flash_disabler();
  if(WiFi.status() != WL_CONNECTED) {
  dnsServer.processNextRequest();
  server.handleClient();
  }
  if(!ap_mode_flag) {
  if(getLocalTime(&timeinfo)){
  if(!schedule_feed_state && printLocalTime("%H").toInt() == scheduled_time_arr[0] && printLocalTime("%M").toInt() == scheduled_time_arr[1]) {
   //camera_disable_out_clock();
  // delay(10);
   schedule_feed_state=true;
   feed_fish(feed_sizes[feedsize_f],chat_id_to_response);
   lastFeedTime = printLocalTime("%B %d %H:%M:%S");
    } else if(schedule_feed_state && printLocalTime("%M").toInt() != scheduled_time_arr[1]) { schedule_feed_state=false; }
  }
  if (digitalRead(inPins) == HIGH && (esp_timer_get_time()/1000000) > 10 ) {
    buttonPressed();
    } else {
   pressedtime = 0;
   scndtimer = 0;
  }
  if(WiFi.status() != WL_CONNECTED) { connectWifi(); } else {
  if (millis() - bot_lasttime > BOT_MTBS)
  {
    int numNewMessages = bot.getUpdates(bot.last_message_received + 1);
    while (numNewMessages)
    {
      Serial.println("got response");
      handleNewMessages(numNewMessages);
      numNewMessages = bot.getUpdates(bot.last_message_received + 1);
    }
    detacher();
    flash_disabler();
    bot_lasttime = millis();
   }
  }
 }
}
